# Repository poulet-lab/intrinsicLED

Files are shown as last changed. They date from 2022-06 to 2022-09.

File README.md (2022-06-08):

# intrinsicLED
 
# BOM (incomplete)
* https://octopart.com/16svpf1000m-panasonic-29498310
* https://octopart.com/dev-13305-sparkfun-66786787
* https://octopart.com/54-00129-tensility-96405015
* https://octopart.com/pec11r-4230k-s0024-bourns-82267986
* https://octopart.com/39502-1003-molex-655380
* https://octopart.com/39500-0003-molex-657436

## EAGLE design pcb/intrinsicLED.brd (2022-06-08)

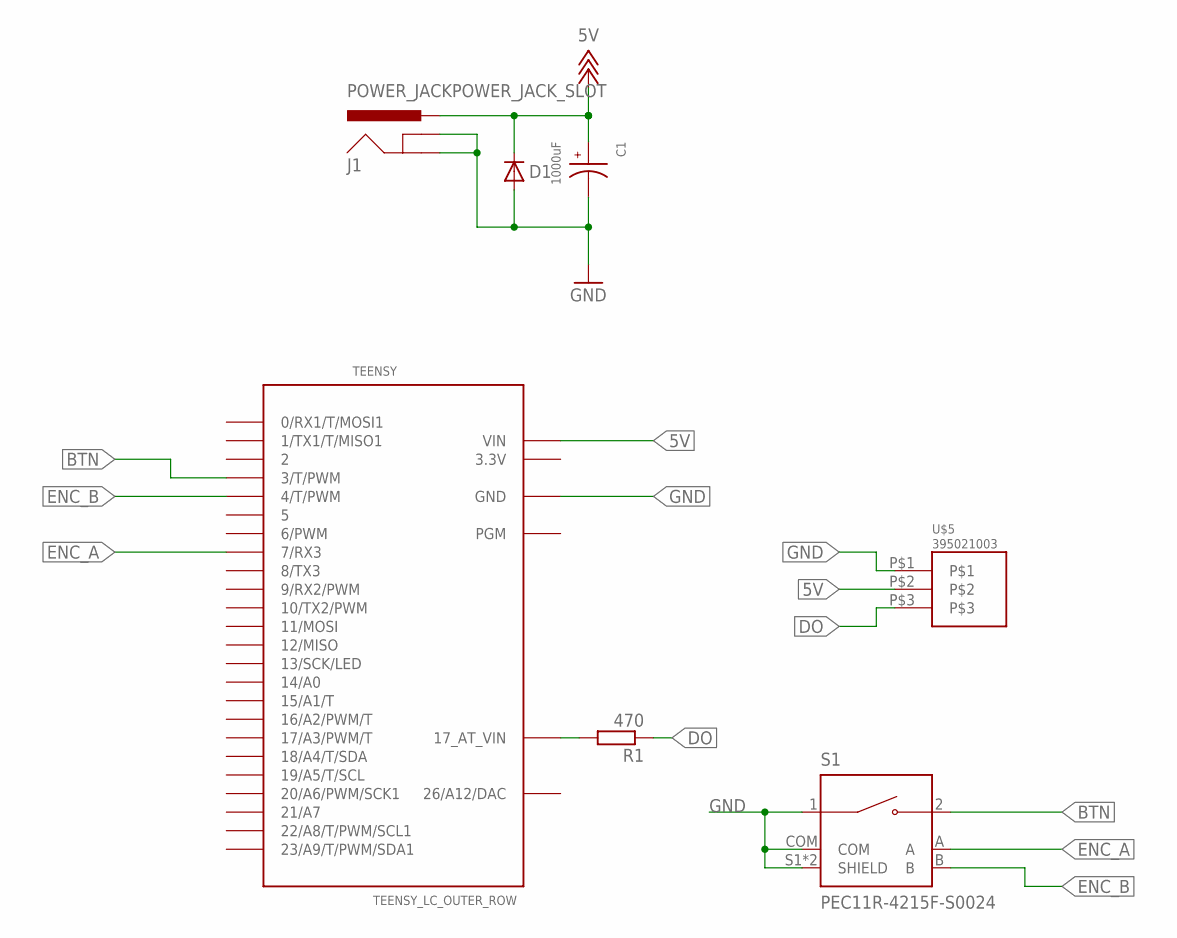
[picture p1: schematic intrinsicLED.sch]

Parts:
C1: 1000uF; CAP_16SVPF1000M
D1: DIODE-DO214AA; DO214AA
J1: POWER_JACKPOWER_JACK_SLOT; POWER_JACK_PTH_SLOT
R1: 470; R1206
S1: PEC11R-4215F-S0024; XDCR_PEC11R-4215F-S0024
TEENSY: TEENSY_LC_OUTER_ROW; TEENSY_3.0-3.2&LC_OUTER_ROW
U$5: 395021003

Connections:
3.3V: TEENSY.3.3V, TEENSY.3.3V1 (3.3V)
5V: C1.1, D1.C, J1.PWR, TEENSY.VIN, U$5.P$2
26/A12/DAC: TEENSY.RESET/DAC (26/A12/DAC)
BTN: S1.2, TEENSY.3 (3/T/PWM)
DO: R1.1, U$5.P$3
ENC_A: S1.A, TEENSY.7 (7/RX3)
ENC_B: S1.B, TEENSY.4 (4/T/PWM)
GND: C1.2, D1.A, J1.GND, J1.GNDBREAK, S1.1, S1.COM, S1.S1 (SHIELD), S1.S2 (SHIELD), TEENSY.AGND (GND), TEENSY.GND, TEENSY.GND1 (GND), U$5.P$1
unnamed: R1.2, TEENSY.VBAT (17_AT_VIN)

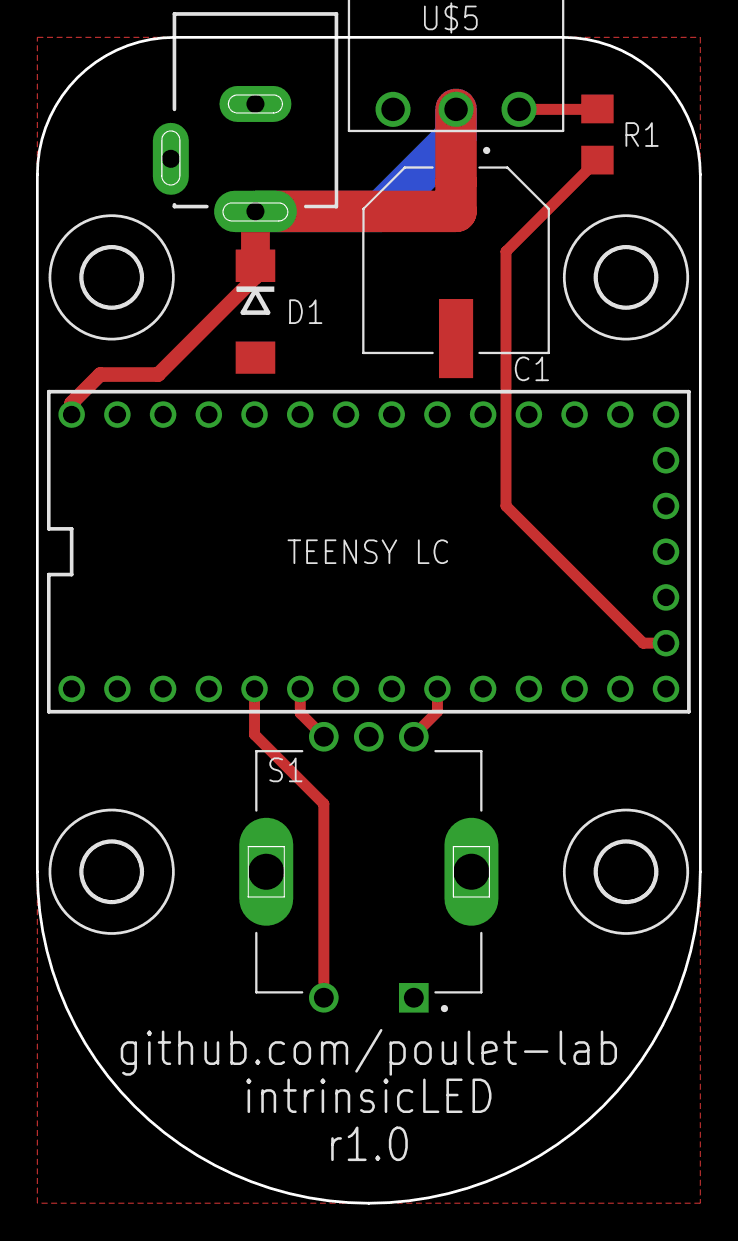
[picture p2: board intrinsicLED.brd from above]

Board: 2 copper layers, 36.8 x 64.8 mm, 11 parts (0 on the bottom side), 8 nets.

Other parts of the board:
U$1, U$2, U$3, U$4: 3,2

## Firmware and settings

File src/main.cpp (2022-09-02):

#include <Arduino.h>
#include <EEPROM.h>
#include <FastLED.h>
#include "EncoderTool.h"
using namespace EncoderTool;

#define PINLED   17
#define PINBTN    3
#define PINENCA   4
#define PINENCB   7

#define OFF       0
#define WHITE     1
#define GREEN     2
#define RED       3

#define PRESSED   0
#define RELEASED  1

#define CPU_RESTART_ADDR (uint32_t *)0xE000ED0C
#define CPU_RESTART_VAL 0x5FA0004
#define CPU_RESTART (*CPU_RESTART_ADDR = CPU_RESTART_VAL);

uint8_t nLeds;
int8_t dir = 0;
CRGB leds[24];
int16_t brightness[] = {0, 128, 255, 255};
int16_t limits[] =     {0, 128, 255, 255};     // limits for brightness
int16_t stepsize[] =   {0,   2,   4,   4};     // increment per detent
uint8_t hue = 96;
uint8_t chipset = 0;

PolledEncoder enc;

uint8_t mode    = OFF;
bool changes    = true;
bool pressTurn  = false;
uint32_t timeStamp = 0;

void cbButton(int state) {
  static bool firstRun = true;
  
  if (firstRun) {
    firstRun = false;
    return;
  }
  if (state==RELEASED) {
    if (pressTurn)
      pressTurn = false;
    else {
      mode = (mode + 1) % 4;
      changes = true;
    }
  } else if (mode==OFF)
    timeStamp = millis();
}

void cbEncoder(int state, int delta) {
  if (enc.getButton()==RELEASED && mode > 0) {
    int16_t newBrightness = brightness[mode] + delta * stepsize[mode];
    newBrightness = constrain(newBrightness, 0, limits[mode]);
    if (newBrightness != brightness[mode]) {
      brightness[mode] = newBrightness;
      changes = true;
    }
  } else if (enc.getButton()==PRESSED && mode == GREEN) {
    pressTurn = true;
    uint8_t newHue = hue - delta * 4;
    newHue = constrain(newHue, 96, 160);
    if (newHue != hue) {
      hue = newHue;
      changes = true;
    }
  } else if (enc.getButton()==PRESSED && mode == WHITE) {
    pressTurn = true;
    int8_t newDir = ((nLeds+1) + (dir+delta) % (nLeds+1)) % (nLeds+1);
    if (newDir != dir) {
      dir = newDir;
      changes = true;
    }
  }
}

void setup() {
  Serial.begin(9600);

  chipset = EEPROM.read(0);
  if (chipset > 1) {
    chipset = 0;
    EEPROM.update(0, chipset);
  }
  switch (chipset) {
    case 0:
      nLeds = 3;
      FastLED.addLeds<WS2811,PINLED>(leds, nLeds);
      break;
    case 1:
      nLeds = 24;
      FastLED.addLeds<NEOPIXEL,PINLED>(leds, nLeds);
      break;
  }
  FastLED.showColor(CRGB::Black);

  enc.begin(PINENCA, PINENCB, PINBTN, CountMode::quarter, INPUT_PULLUP);
  enc.attachCallback(cbEncoder);
  enc.attachButtonCallback(cbButton);
}

void loop() {
  enc.tick();

  if (changes) {
    switch (mode) {
      case OFF:
        FastLED.showColor(CRGB::Black);
        break;
      case WHITE:
        if (dir==0)
          FastLED.showColor(CRGB::White, brightness[mode]);
        else {
          leds[dir-1] = CRGB::White;
          FastLED.setBrightness(brightness[mode]);
          FastLED.show();
          leds[dir-1] = CRGB::Black;
        }
        break;
      case GREEN:
        FastLED.showColor(CHSV(hue, 255, brightness[mode]));
        break;
      case RED:
        FastLED.showColor(CRGB::Red, brightness[mode]);
    }
    changes = false;

  } else if (mode==OFF && enc.getButton()==PRESSED && millis()-timeStamp>10000) {
    chipset = (chipset + 1) % 2;
    EEPROM.update(0, chipset);
    FastLED.showColor(CRGB::White, 32);
    delay(50);
    FastLED.showColor(CRGB::Black);
    delay(50);
    FastLED.showColor(CRGB::White, 32);
    delay(50);
    FastLED.showColor(CRGB::Black);
    CPU_RESTART;
  }
}

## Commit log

2022-06-08 PCB r1.0
    [intrinsicLED.brd, intrinsicLED.sch]
2022-08-25 implemented switching between WS2811 and NEOPIXEL chipsets
2022-08-25 limit maximum brightness of white mode
    to avoid overheating of the LED
    [main.cpp]

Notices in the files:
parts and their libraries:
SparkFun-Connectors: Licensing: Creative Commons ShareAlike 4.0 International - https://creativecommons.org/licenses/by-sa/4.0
